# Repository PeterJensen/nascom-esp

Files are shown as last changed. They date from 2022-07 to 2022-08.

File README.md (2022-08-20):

A hardware emulator for the Nascom-2 computer running on an ESP-32 with:
* VGA for display output
* PS/2 keyboard for input
* SD card reader for tape input/output

## History
The Nascom-2 was an early (1979) Z80 based micro.  Most machine were homebuilt from a kit: https://en.wikipedia.org/wiki/Nascom_(computer_kit)

The one I built 40+ years ago still runs!

## Specs
The specs of a typical machine:
* 4MHz Z80 (an 8080 compatible chip from Zilog)
* 8K static RAM on motherboard
* 64K dynamic RAM on extension board
* Cassette tape used for storage
* NAS-SYS monitor in ROM (2K) 
* Microsoft Basic in ROM (8K)

## Software
Lots of excellent software was written for this machine; including Assemblers/Disassemblers, Pascal editors/compilers, text formatters, games, etc.

The BLS Pascal compiler/editor deserves a special mention.  In my opinion, this is one of the most impressive pieces of software written. It was implemented by Anders Hejlsberg.  It is the origin of the Turbo Pascal and Delphi lineage of Pascal (-like) compilers and generates executable Z80 code. It allows code to be written with a full screen editor, which was a major leap in programmer productivity at the time. A welcome reprive from the line-by-line editing for Basic programs. The compiler and editor was implemented in **12K of code**. You'll be hard pressed to write a hello-world program and compile it into less code with today's 'modern' development environments.

An excellent resource/archive for software is Tommy Thorn's [nascomhomepage](http://www.nascomhomepage.com).

## Diagram
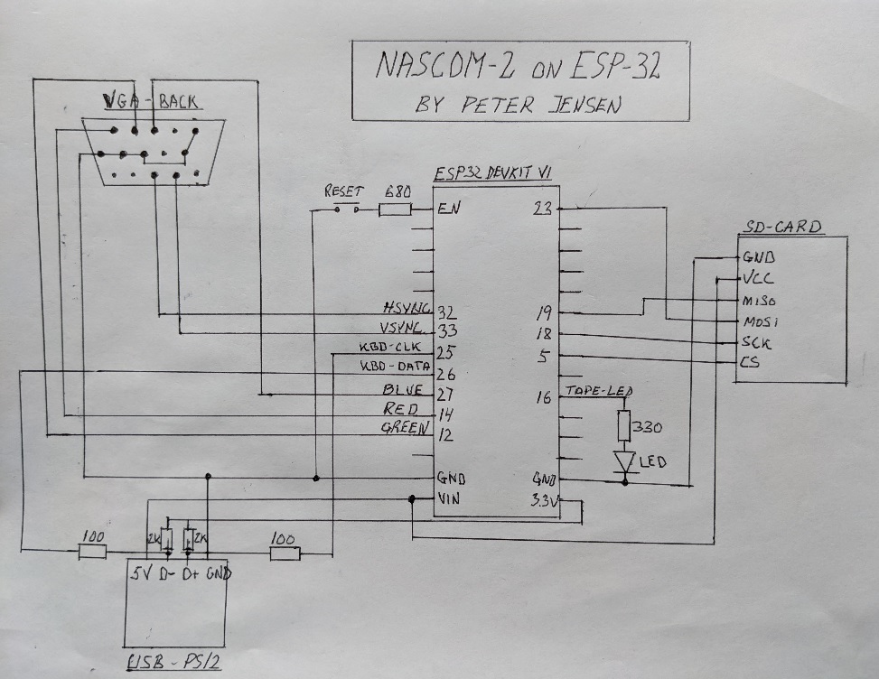
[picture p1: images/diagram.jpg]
Diagram


## Box
openSCAD was used to design a box, which can be printed on a 3D printer. I'm using the Creality Ender-3 printer, a very good budget printer (~$300).

I use openSCAD because doing the designs is much like writing code, so I don't have to step out of my comfort zone.

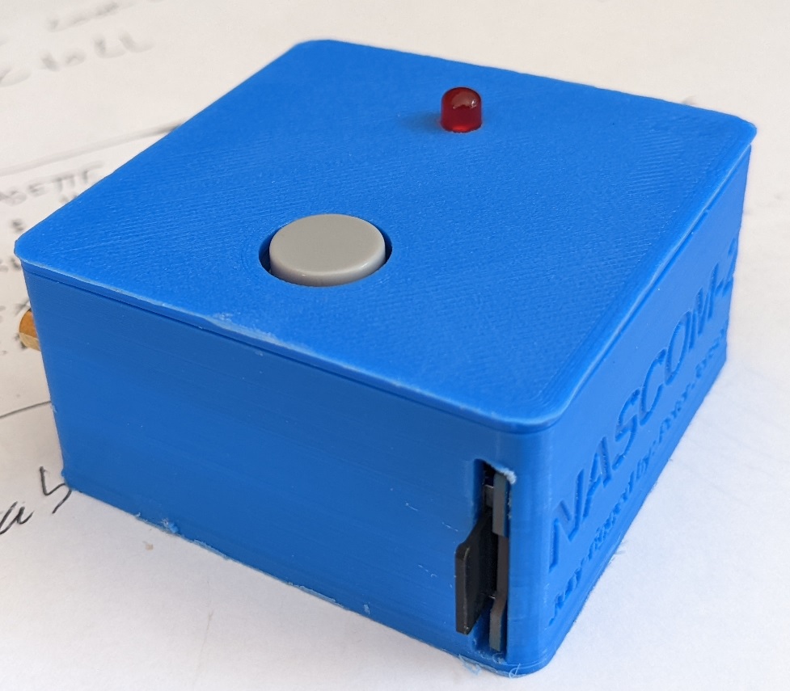
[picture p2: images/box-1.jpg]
Box 1

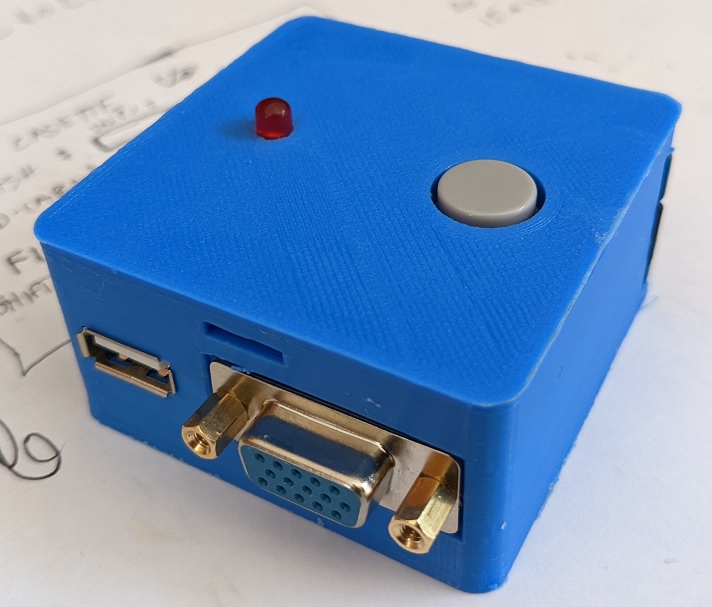
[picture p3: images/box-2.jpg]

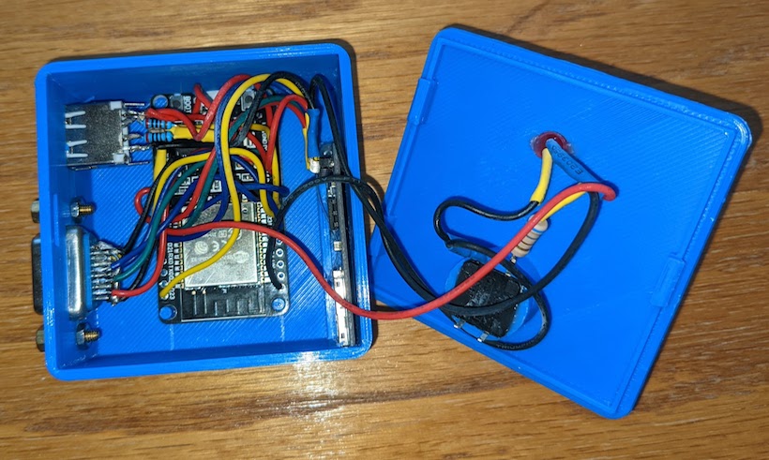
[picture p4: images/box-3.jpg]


## Screenshots
**Boot Screen**
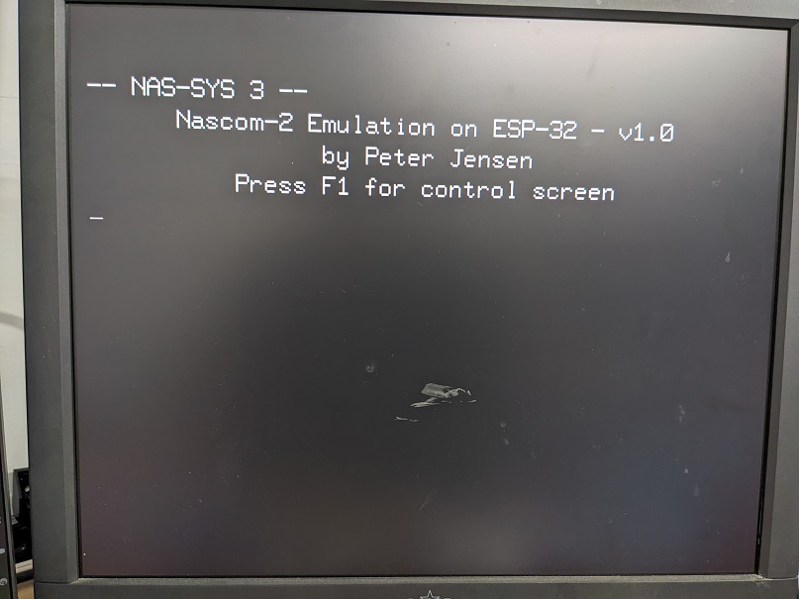
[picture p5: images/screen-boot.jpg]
Screen Boot


**Control Screen**
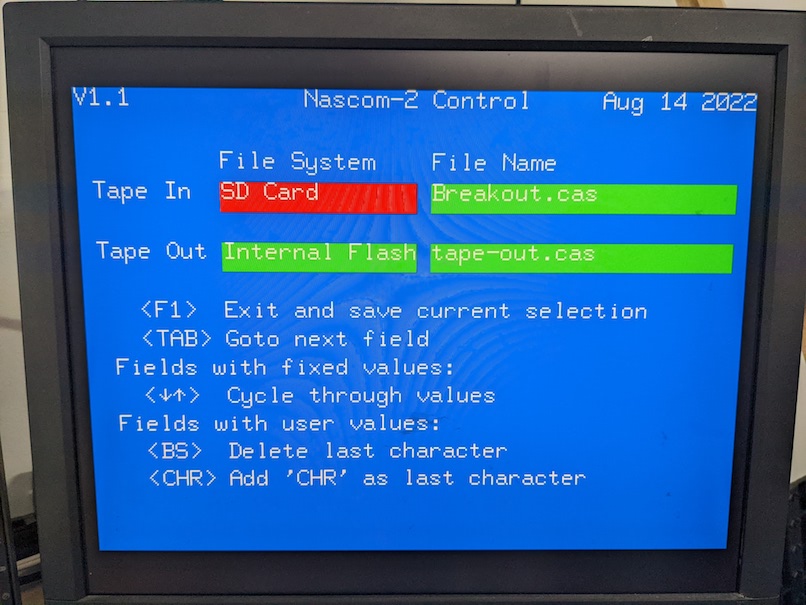
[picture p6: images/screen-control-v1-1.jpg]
Screen Control


**Loading and running BLS Pascal**
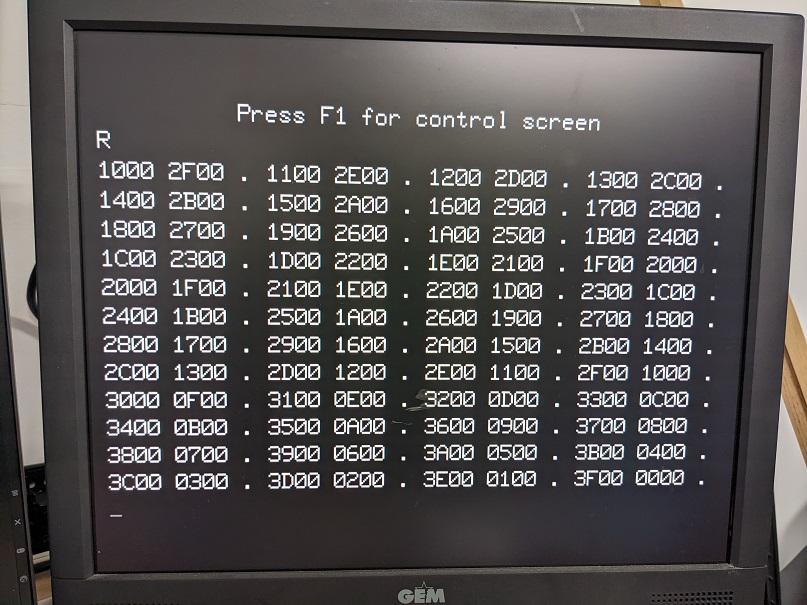
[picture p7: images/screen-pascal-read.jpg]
Screen Pascal Read

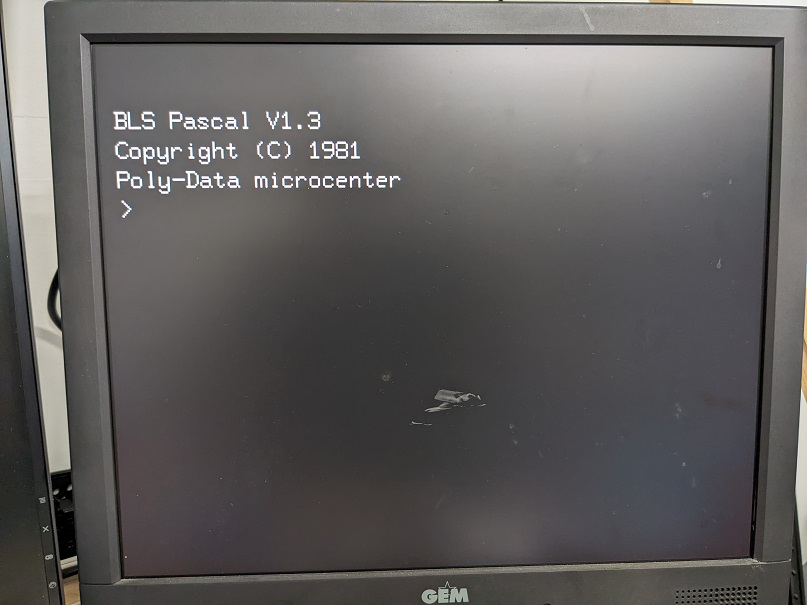
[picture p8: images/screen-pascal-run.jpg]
Screen Pascal Run

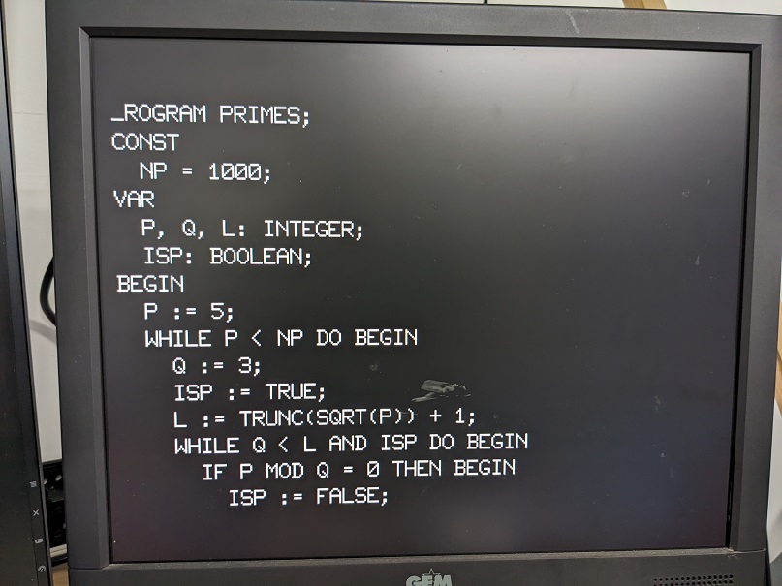
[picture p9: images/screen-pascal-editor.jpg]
Screen Pascal Editor

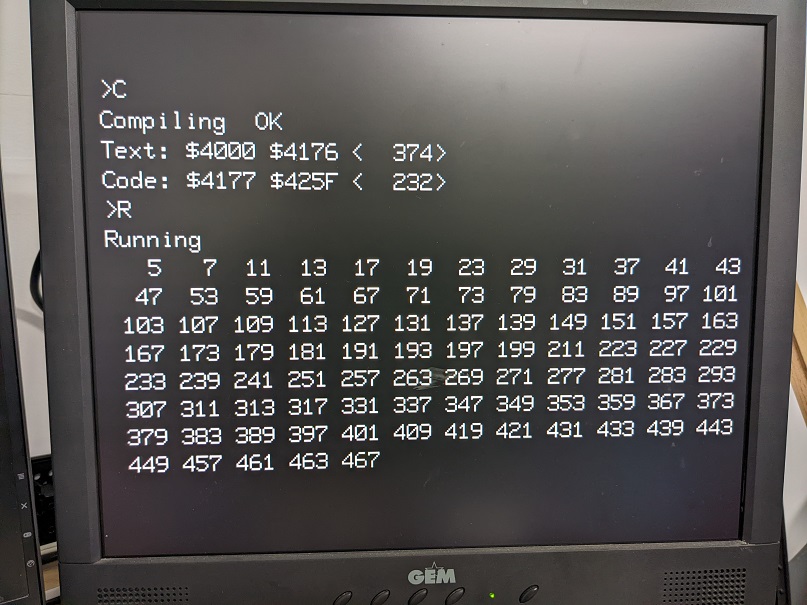
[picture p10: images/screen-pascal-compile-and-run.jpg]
Screen Pascal Compile


**NAP Assembler**
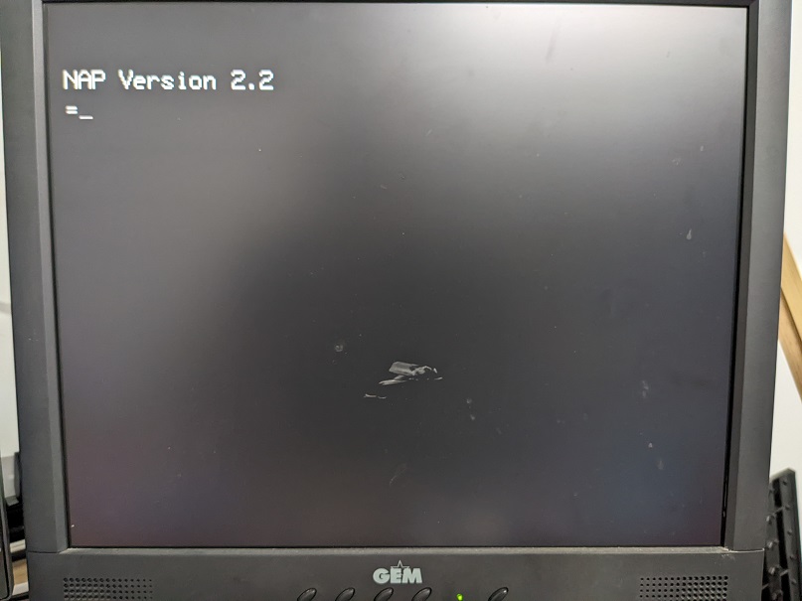
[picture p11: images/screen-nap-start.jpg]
Screen NAP

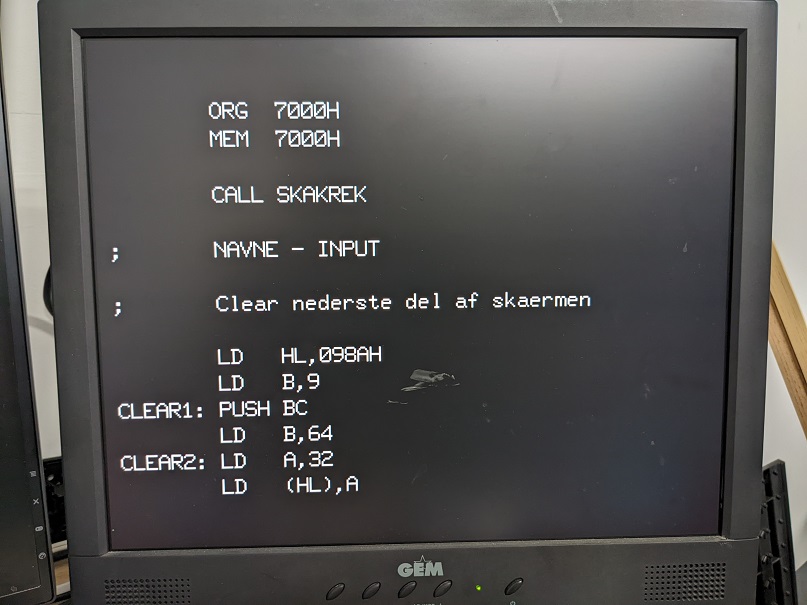
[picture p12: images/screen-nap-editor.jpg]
Screen NAP Editor

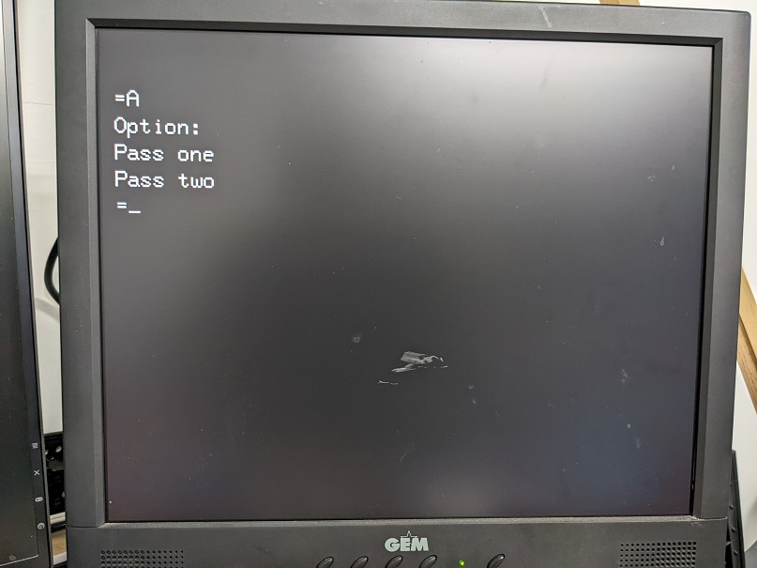
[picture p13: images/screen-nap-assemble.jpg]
Screen NAP Assemble

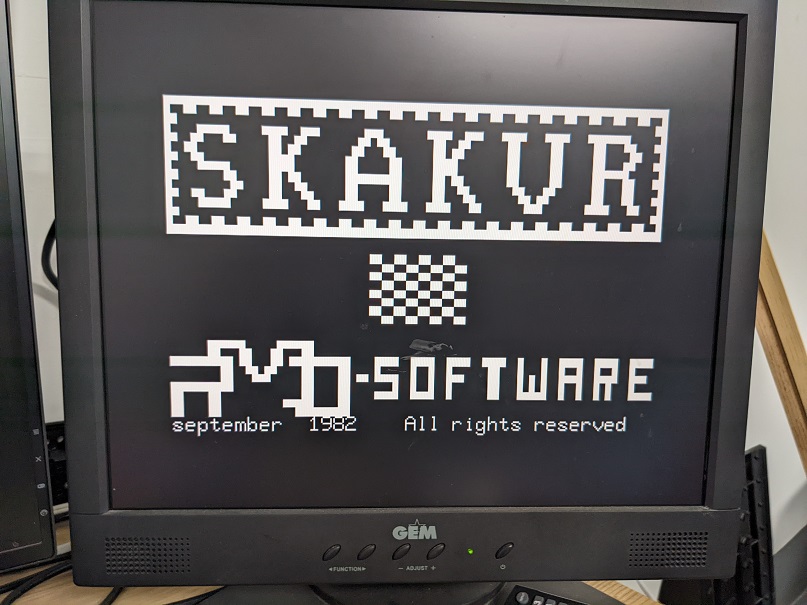
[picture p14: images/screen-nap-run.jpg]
Screen NAP Run


**Microsoft Basic**
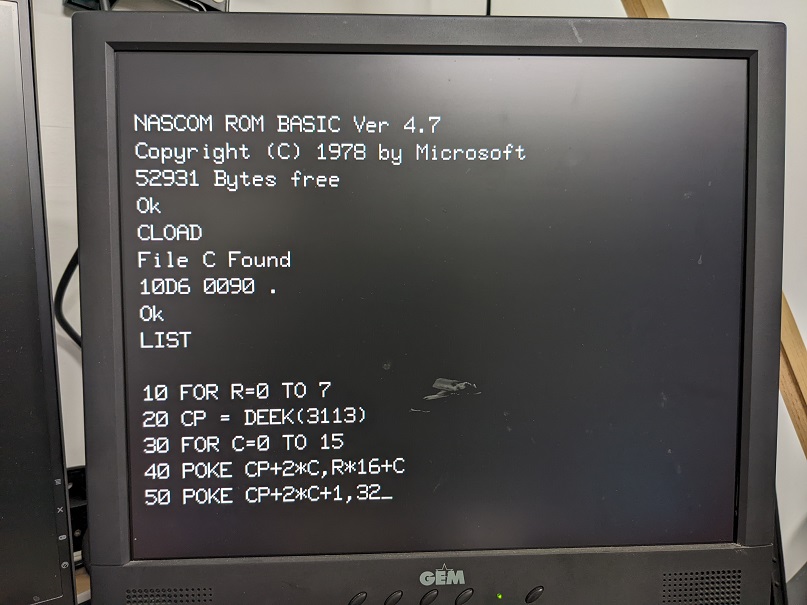
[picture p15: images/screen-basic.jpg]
Screen Basic Startup

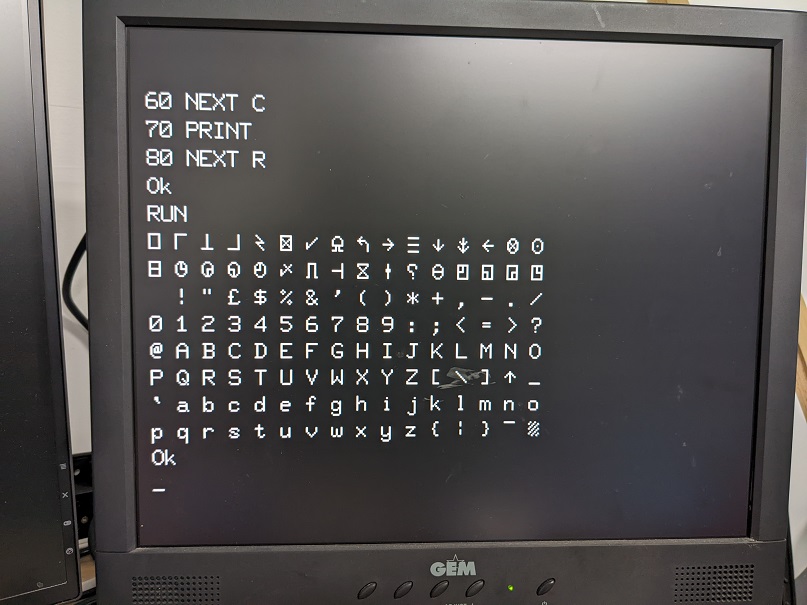
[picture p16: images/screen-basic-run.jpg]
Screen Basic Run


**nasForth**

Forth was also available on the Nascom-2.  Several implementations were made.  There's three (HullForth, nasForth, and T-Forth) on [nascomhomepage](http://www.nascomhomepage.com).  I've added nasForth to the permanent selection in the Internal Flash.

The Forth programming system had an innovative way of allowing the user to progressively develop their programs through compilation of word definitions and invocation of those definitions via a runtime interpreter.

With that said, I wouldn't recommend using Forth for anything substantial.  As a programming language, it has many drawbacks; mainly it's hard to write and read.  It took me many hours to get the PRIMES algorithm below working, and I even had a headstart, because I found some code on Youtube from [ForthFreak](https://www.youtube.com/watch?v=V5VGuNTrDL8).  I'm not a seasoned Forth programmer, though.  Not a Forth programmer at all, actually.  It is a great language, if you want to impress friends and colleagues with your mad obscure coding skills.

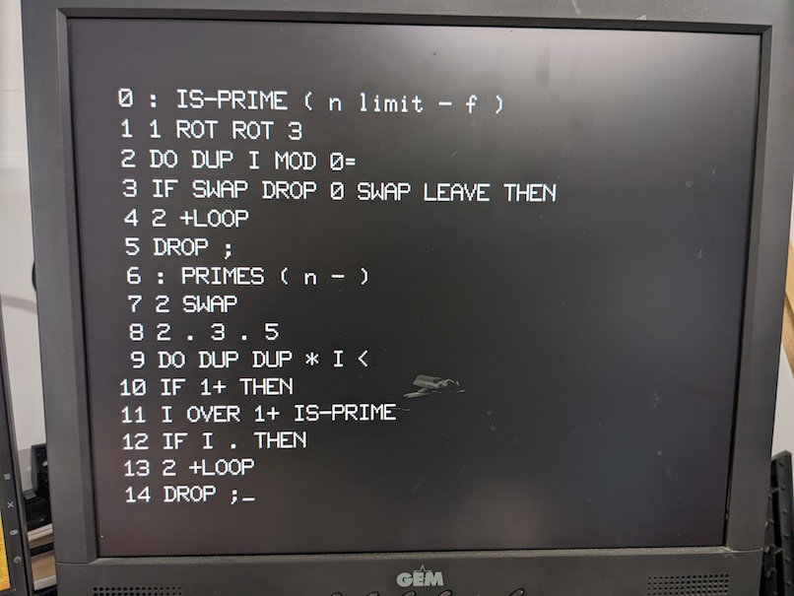
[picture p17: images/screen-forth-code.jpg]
Screen Forth Code

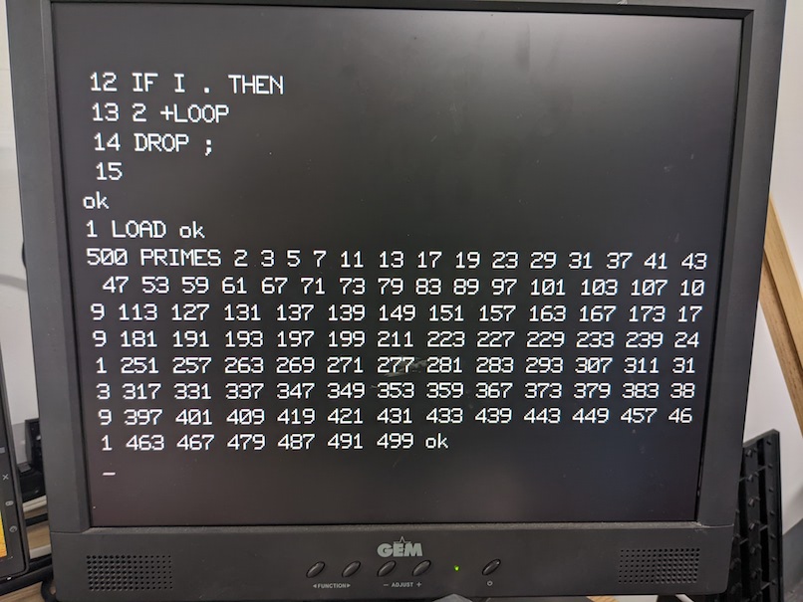
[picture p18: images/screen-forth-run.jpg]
Screen Forth Run


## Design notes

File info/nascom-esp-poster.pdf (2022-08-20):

# NASCOM-2 Replica on ESP32

by Peter Jensen
Specs:
- ESP32 Devkit V1
- VGA Display
- PS/2 Keyboard
- SD card for cassette tape emulation
- Runs all legacy NASCOM-2 software via Z80 emulator

ESP32-WROOM-32 specs:
- Xtensa dual-core32-bit LX6 microprocessor, operating at 160 or 240 MHz
- Ultra low power (ULP) co-processor (handles PS/2 keyboard)
- 512K RAM (roughly 320K available)
- Flash Memory: 4M
- Runs FreeRTOS

Software:
- Microsoft Basic (anno 1978)
- Assemblers/Disassemblers
- Pascal Compiler (12K)
- Forth
- Games

Notes:
- The screen refreshes at 30fps.
- Accurate execution timing requires a ~25ms delay for each frame.
- Idling 75% of the time (25/33).
- The ESP32 has plenty of headroom when emulating a 4MHz Z80.

More Info:
- https://github.com/PeterJensen/nascom-esp

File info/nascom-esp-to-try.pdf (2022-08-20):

# NASCOM-2 on ESP32: Things to try

1. Play BLS Super Maanelander:
1.1. Press RESET - Button on top of box
1.2. Type ‘E1000’ - Start executing at address 1000H. Code is pre-loaded
2. Compile and Run a Pascal program:
2.1. | Press <F1> | - Select ‘blspascal13.cas’ from the Internal Flash for ‘Tape In’
2.2. | Press <F1> | - Exit control screen
2.3. | Type ‘R’ | - Read the BLS Pascal Compiler/Editor
2.4. Type ‘E1000’ - Start the BLS Pascal Compiler/Editor program
2.5. | Press <F1> | - Select ‘primes.pas’ from the Internal Flash for ‘Tape In’
2.6. | Press <F1> | - Exit control screen
2.7. | Type ‘L’ | - Load the primes.pas Pascal source into memory
2.8. | Type ‘E’ | - Start the editor to inspect the Pascal code
2.9. Type ‘CTRL/X’- Exit the editor
2.10. | Type ‘C’ | - Compile the source code
2.11. | Type ‘R’ | - Run the compiled code
2.12. | Type ‘E’ | - Invoke the editor
2.13. | Make edits | - Can you make it run faster? Use SHIFT/Arrow Keys to insert
| | or delete characters and lines.
3. Microsoft Basic:
3.1. | Press <F1> | - Select ‘primes.bas’ from the Internal Flash for ‘Tape In’
3.2. | Press <F1> | - Exit control screen
3.3. | Type ‘J’ | - Start Microsoft Basic
3.4. Type ‘CLOAD’ - Load the primes.bas basic program
3.5. | Type ‘LIST’ | - See the program source
3.6. | Type ‘RUN’ | - Run the program
3.7. | Make edits | - Insert lines by typing in a line number followed by some Basic
| | command.
4. nasForth (Forth system)
4.1. | Press <F1> | - Select ‘NForth.cas’ from the Internal Flash for ‘Tape In’
4.2. | Press <F1> | - Exit control screen
4.3. | Type ‘R’ | - Read the nasForth program
4.4. | Press <F1> | - Select the ‘primes.for’ from the Interna Flash for ‘Tape In’
4.5. | Type ‘R’ | - Read the Forth example code into memory
4.6. Type ‘E1000’ - Start the nasForth program
4.7. Type ‘1 LIST’ - Shows the two word definitions for IS-PRIME and PRIMES
4.8. Type ‘1 LOAD’- Loads/compiles the code
4.9. Type ‘200 PRIMES’ - Find all primes less than 200

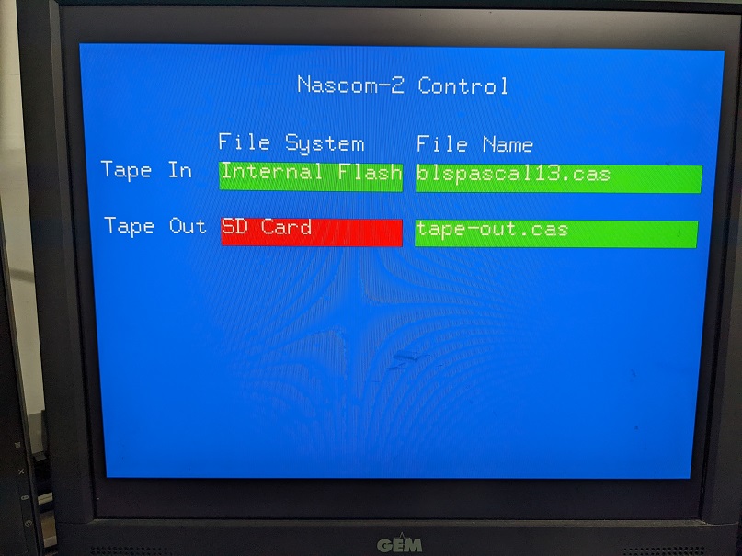
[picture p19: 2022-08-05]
images/screen-control.jpg

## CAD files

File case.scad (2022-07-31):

// Author: Peter Jensen

$fn = 50;
x = 0; y = 1; z = 2;

boxOuterDims        = [60.0, 60.0, 32.0];
boxWall             = 2;
boxInnerDims        = [boxOuterDims[x] - 2*boxWall, boxOuterDims[y] - 2*boxWall, boxOuterDims[z] - 2*boxWall];

esp32Dims           = [51.6, 28.2, 5.7];
esp32Offsets        = [boxOuterDims[x]/2 - esp32Dims[x]/2, 0, -boxInnerDims[z]/2 + esp32Dims[z]/2];
vgaPlateDims        = [31.8, 1.0, 13.4];
vgaConnectorDims    = [19.0, 16.5, 10.8];
vgaConnectorOffsets = [0, 6.2 - vgaConnectorDims[y]/2, 0];
vgaOffsets          = [-10.0, boxOuterDims[y]/2 - vgaPlateDims[y]/2, 0];
usbDims             = [13.0, 18.0, 5.6];
usbOffsets          = [18.0, boxOuterDims[y]/2 - usbDims[y]/2, vgaOffsets[z]];
sdDims              = [42.3, 3.0, 23.5];
sdPins              = [8.9, 6.5, 15.0];
sdBraceDims         = [sdDims[x] + 1, sdDims[y] + 3, 3];
sdBraceOffsets      = [-boxInnerDims[x]/2 + sdBraceDims[x]/2, -boxInnerDims[y]/2 + sdBraceDims[y]/2, -boxInnerDims[z]/2 + sdBraceDims[z]/2];
sdPinsOffsets       = [sdDims[x]/2 + sdPins[x]/2 - 5.2, -sdDims[y]/2 + sdPins[y]/2 - 1.0, 0];
sdOffsets           = [-boxOuterDims[x]/2 + sdDims[x]/2, -boxInnerDims[y]/2 + sdDims[y]/2 + 1, -boxInnerDims[z]/2 + sdDims[z]/2];
esp32HolesD         = 3;
esp32HolesOffset    = [2 - esp32Dims[x]/2, 2 - esp32Dims[y]/2, -esp32Dims[z]/2];
vgaHolesD           = 3.3;
vgaHolesOffsets     = [12.5, 0, 0];

// Reset switch/mount
switch2BaseDims     = [11.9, 11.9, 3.1];
switch2StemD        = 6.6;
switch2StemH        = 3.1;
switch2TopD         = 12.9;
switch2TopH         = 5.7;
switch2Z            = switch2BaseDims[z] + switch2StemH + switch2TopH - 1;
switchCylT          = 0.5;
  
module switch2() {
  translate([0, 0, switch2BaseDims[z]/2]) {
    cube(switch2BaseDims, center = true);
    translate([0, 0, switch2BaseDims[z]/2])
      cylinder(d = switch2StemD, h = switch2StemH, $fn = 40);
    translate([0, 0, switch2BaseDims[z]/2 + switch2StemH])
      cylinder(d = switch2TopD, h = switch2TopH, $fn = 40);
  }
}

switch2CylT      = 1.2;
switch2CylMargin = 1.0;
switch2CylZ      = switch2Z;
switch2CylD      = switch2TopD + switch2CylMargin;

resetMountOffsets = [-boxOuterDims[x]/4, 0, boxOuterDims[z]/2 - switch2Z];

module switch2Cyl() {
  translate([0, 0, 0]) {
    difference() {
      cylinder(d = switch2CylD + 2*switch2CylT, h = switch2Z, $fn = 40);
      translate([0, 0, switch2BaseDims[z]])
        cylinder(d = switch2CylD, h = switch2Z, $fn = 40);
      translate([0, 0, switch2BaseDims[z]/2])
        cube(switch2BaseDims, center = true);
    }
  }
}

module resetMount(cut = false, show = false) {
  translate(resetMountOffsets) {
    if (show)
      switch2();
    switch2Cyl();
    if (cut)
      cylinder(d = switch2CylD + 2*switchCylT, h = switch2CylZ);
  }
}

// Slots for top
slotZ        = 2;
slot1Dims    = [10, 2, 2];
slot1Offsets = [0, boxInnerDims[y]/2 + slot1Dims[y]/2, boxInnerDims[z]/2 - slot1Dims[z]/2 - slotZ];

slots2Dims    = [10, 1, 2];
slots2Offsets = [0, -boxInnerDims[y]/2 - slots2Dims[y]/2, boxInnerDims[z]/2 - slots2Dims[z]/2 - slotZ];
slots2Dist    = 30;

module slot1() {
  translate(slot1Offsets)
    cube(slot1Dims, center = true);
}

module slots2() {
  translate(slots2Offsets) {
    translate([-slots2Dist/2, 0, 0]) cube(slots2Dims, center = true);
    translate([slots2Dist/2, 0, 0]) cube(slots2Dims, center = true);
  }
}

module slots() {
  slot1();
  slots2();
}

boxRimDims = [boxInnerDims[x], boxInnerDims[y], 2];
boxRimInnerDims = boxRimDims - [2, 2, 0];

tapY1 = slot1Dims[z] + slotZ;
tapX2 = 2;
tapY2 = tapY1;
tapX3 = tapX2 + 1;
tapY3 = tapY2 - 1;
tapX4 = tapX2;
tapY4 = tapY3 - 1;
tapX5 = tapX2;
tapPoints = [[0, 0], [0, tapY1], [tapX2, tapY2], [tapX3, tapY3], [tapX4, tapY4], [tapX5, 0]];
tapW  = slot1Dims[x] - 1;

module tap() {
  rotate([-90, 0, 0])
    translate([0, 0, -tapW/2])
      linear_extrude(height = tapW)
        polygon(tapPoints);
}

module taps() {
  xOffset1 = boxRimDims[y]/2 - tapX2/2 - 0.5;
  xOffset2 = -boxRimDims[y]/2 + tapX2/2;
  yOffset  = boxRimDims[x]/2 - tapX2;
  zOffset  = boxInnerDims[z]/2;
//  tap();
  translate([0, yOffset, zOffset]) rotate([0, 0, 90]) tap();
  translate([slots2Dist/2, -yOffset, zOffset]) rotate([0, 0, -90]) tap();
  translate([-slots2Dist/2, -yOffset, zOffset]) rotate([0, 0, -90]) tap();
}


module esp32Holes(d = esp32HolesD) {
  translate(esp32HolesOffset)
    cylinder(d=d, h=esp32Dims[z]);
  translate([esp32HolesOffset[x], -esp32HolesOffset[y], esp32HolesOffset[z]])
    cylinder(d=d, h=esp32Dims[z]);
}

module esp32() {
  translate(esp32Offsets)
    difference() {
      cube(esp32Dims, center=true);
      esp32Holes();
    }
}

module vgaHoles(d = vgaHolesD) {
  module oneHole() {
    h = vgaPlateDims[y] + 5;
    translate([0, h/2, 0])
      rotate([90, 0, 0])
        cylinder(d = d, h = h);
  }
//  translate(vgaOffsets) {
    translate(vgaHolesOffsets)
      oneHole();
    translate([-vgaHolesOffsets[x], vgaHolesOffsets[y], vgaHolesOffsets[z]])
      oneHole();
//  }
}

module vga() {
  translate(vgaOffsets) {
    difference() {
      cube(vgaPlateDims, center=true);
      vgaHoles();
    }
    translate(vgaConnectorOffsets)
      cube(vgaConnectorDims, center=true);
  }
}

module usb() {
  translate(usbOffsets)
    cube(usbDims, center=true);
}

module sd() {
  translate(sdOffsets) {
    cube(sdDims, center=true);
    translate(sdPinsOffsets)
      cube(sdPins, center=true);
  }
}

module sdBrace() {
  difference() {
    translate(sdBraceOffsets)
      cube(sdBraceDims, center=true);
    sd();
  }
}

module components() {
    esp32();
    vga();
    usb();
    sd();
    translate(vgaOffsets)
      vgaHoles();
}


module roundedBox(dims, radius) {
  module cut() {
    difference() {
      cube([2*radius, 2*radius, dims[z]], center=true);
      translate([radius, radius, -dims[z]/2])
        cylinder(r=radius, h=dims[z], $fn=50);
    }
  }
  difference() {
    cube(dims, center=true);
    translate([-dims[x]/2, -dims[y]/2, 0])
      cut();
    translate([-dims[x]/2, dims[y]/2, 0])
      rotate([0, 0, -90]) cut();
    translate([dims[x]/2, -dims[y]/2, 0])
      rotate([0, 0, 90]) cut();
    translate([dims[x]/2, dims[y]/2, 0])
      rotate([0, 0, 180]) cut();
  }
}

module boxText(str, size = 8) {
  rotate([90, 0, 0])
    linear_extrude(height = 5)
      text(str, font="Ariel:style=Bold", size, halign="center", valign="center", spacing=0.95);
}

module nascomText() {
  translate([0, -boxOuterDims[y]/2 + 0.5, 5])
    boxText("NASCOM-2", 7.5);
}

module madeByText() {
  translate([0, -boxOuterDims[y]/2 + 0.5, -5])
    boxText("Jury-rigged by: Peter Jensen", 3);
}

module serialNoText() {
  translate([0, -boxOuterDims[y]/2 + 0.5, -11])
    boxText("Serial No.: 3", 3);
}
  
module boxBottom() {
  color([0.3, 0.5, 0.8, 1.0]) {
    difference() {    
      roundedBox(boxOuterDims, 4);
      cube(boxInnerDims, center=true);
      nascomText();
      madeByText();
      serialNoText();
      components();
      slots();
      translate([0, 0, boxOuterDims[z] - boxWall])
        cube(boxOuterDims, center=true);
    }
    sdBrace();
    translate(esp32Offsets)
      esp32Holes(esp32HolesD - 0.5);
  }
}

module boxTopRim() {
  translate([0, 0, boxInnerDims[z]/2 - boxRimDims[z]/2])
    difference() {
      cube(boxRimDims, center = true);
      cube(boxRimInnerDims, center = true);
    }
}

ledD = 4.9;
ledOffsets = [boxOuterDims[x]/4, 0, boxInnerDims[z]/2 + boxWall/2];
module led() {
  translate(ledOffsets)
    cylinder(d=ledD, h=boxWall, center=true);
}

module boxTop() {
  difference() {
    roundedBox(boxOuterDims, 4);
    translate([0, 0, -boxWall])
      cube(boxOuterDims, center=true);
    resetMount(true);
    led();
  }
  boxTopRim();
  resetMount();
  taps();
}

module main() {
  boxBottom();
  //components();
  //boxTop();
  //resetMount();
}

main();

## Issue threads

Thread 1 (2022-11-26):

Request for help in compiling Nascom-ESP

bob-g4bby, 2022-11-26:
Hi Peter,

I'm a numty when it comes to Visual Studio Code and PlatformIO. I downloaded your four files there - but PlatformIO complains it can't open file ESP32Lib.h nor devdrivers/keyboard.h . I used to have a Nascom and was hoping to emulate it using a TTGO based VGA32 board. I'll need to reassign some pins, but need to get you original code to compile first.

Any help would be appreciated - Bob Edwards, SW U.K.

PeterJensen, 2023-02-26:
Hi Bob,

So sorry for not getting back to you sooner.  I didn't see this issue until just now.

The code makes use of these two libraries:
- bitluni's ESP32Lib: https://github.com/bitluni/ESP32Lib
- Fabrizio Di Vittorio's FabGL: https://github.com/fdivitto/FabGL

You'll need to have a 'clones' directory at the same level as your nascom-esp clone.  Those two repos must be cloned into that clones directory.  Alternatively you can modify platformio.ini to point to where they can be found.

In addition, I've made a few changes to the repos mentioned above, so after you've created the clones you'll need to apply the two patches found in this repo, so something like this:

```
$ cd ESP32Lib
$ git apply ../../nascom-esp/ESP32Lib.patch
$ cd ../FabGL
$ git apply ../../nascom-esp/FabGL.patch

```
Hope this helps
Peter

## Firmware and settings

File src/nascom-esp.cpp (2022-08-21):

// Author: Peter Jensen
//
// NASCOM-2 Simulator running on an ESP32S
//
// The simulator uses a VGA display and a PS/2 keyboard.
// The cassette tape is simulated with both the internal flash and an attached SD card reader.
//
// PlatformIO/VS Code development environment was used for development.
//
// The project uses software from various sources:
//
// 1. Tommy Thorn's virtual-nascom: https://github.com/tommythorn/virtual-nascom:
//    Many concepts and ideas are derived from Tommy's original work:
//    Nascom-2 keyboard simulation:  Original code is mostly rewritten, but the ideas are the same.
//      Tommy's original code was instrumental in getting this right.  Also, his feedback and
//      debugging has been invaluable.
//    Video RAM update: The idea of caching.
//    CPU timing: Controlling timing with delays for each frame.
//    Nascom-2 font definition: Copied directly from above repo.
// 2. bitluni's ESP32Lib: https://github.com/bitluni/ESP32Lib:
//    VGA driver logic:  Made it work with the Nascom-2 font defintion from 1)
// 3. Fabrizio Di Vittorio's FabGL: https://github.com/fdivitto/FabGL:
//    PS/2 keyboard handling: This fabulous library does much more than just handling a PS/2
//      keyboard.  It's also able to handle the VGA and Z80 CPU simulation, but those
//      parts aren't used.  I'm considering using the Z80 simulator, since it tracks clock cycles,
//      so it should be possible to get a more accurate simulation of time.
// 4. Z80 emulator from Frank D. Cringle:
//    There are many Z80 emulator's to choose from.  This is the one used by virtual-nascom, and
//    I use it here as well.  It's been proven to work for NASCOM-2 simulation.
//
// Notes:
//
// 1. The display is set to be refreshed at 30fps. The number of instructions that will execute between
//    each frame is based on roughly 8 cycles per instructions and a clock frequency of 4MHz.
//    The necessary delay for each frame in order to get accurate simulation speed is dynamically
//    determined and turns out to be roughly 25ms.  So for each 33ms (a frame) the ESP32 is idling for
//    25ms. The ESP32 is more than capable of simulating a 4MHz Z80.
//

#include <Arduino.h>
#include <LittleFS.h>
#include <SD.h>
#include <SPI.h>
#include "ESP32Lib.h"
#include "devdrivers/keyboard.h"
#include "NascomFont.h"
#include "simz80.h"

#define VERSION "V1.1"
static const char *version = VERSION;
static const char *buildDate = __DATE__;

namespace z80 {
  // Z80 state
  WORD af[2];                  // accumulator and flags (2 banks)
  int af_sel;                  // bank select for af
  struct ddregs regs[2];       // bc,de,hl
  int regs_sel;                // bank select for ddregs
  WORD ir;                     // other Z80 registers
  WORD ix;
  WORD iy;
  WORD sp;
  WORD pc;
  WORD IFF;
  BYTE ram[MEMSIZE*1024+1];  // The +1 location is for the wraparound GetWord
};

static const char *startText =
  "      Nascom-2 Emulation on ESP-32 - " VERSION "\x17\x14"
  "          Press F1 for control screen\x17\x14";

// Pin configuration
class Pins {
public:
  static const gpio_num_t red      = GPIO_NUM_14;
  static const gpio_num_t green    = GPIO_NUM_12;
  static const gpio_num_t blue     = GPIO_NUM_27;
  static const gpio_num_t hsync    = GPIO_NUM_32;
  static const gpio_num_t vsync    = GPIO_NUM_33;
  static const gpio_num_t kbdClock = GPIO_NUM_25;
  static const gpio_num_t kbdData  = GPIO_NUM_26;
  static const gpio_num_t tapeLed  = GPIO_NUM_16;
  static const gpio_num_t sdSck    = GPIO_NUM_18;
  static const gpio_num_t sdMiso   = GPIO_NUM_19;
  static const gpio_num_t sdMosi   = GPIO_NUM_23;
  static const gpio_num_t sdCs     = GPIO_NUM_5;
};

// Nascom memory
class NascomMemory {
  uint8_t *mem;
public:
  NascomMemory(uint8_t *mem) : mem(mem) {}
  uint8_t *getMemPtr() {
    return mem;
  }
  bool nasFileLoad(const char *fileName) {
    uint16_t addr;
    File     file = LittleFS.open(fileName, "r");
    uint32_t numBytes = 0;
    if (!file) {
      DEBUG_PRINTF("Cannot open: %s\n", fileName);
      return false;
    }
    DEBUG_PRINTF("Loading %s\n", fileName);
    const size_t bufSize = 100;
    char buffer[bufSize];
    while (file.available()) {
      size_t l = file.readBytesUntil('\n', buffer, bufSize-1);
      buffer[l] = 0;
      if (buffer[0] == '.') {
        break;
      }
      char *p = buffer;
      addr  = strtoul(p, &p, 16);
      // DEBUG_PRINTF("%04x:", addr);
      for (uint8_t b = 0; b < 8; b++) {
        uint8_t byte = strtoul(p, &p, 16);
        mem[addr+b] = byte;
        if (addr + b == 0) {
          mem[0x10000] = mem[0]; // make getWord(0xffff) work correctly
        }
        // DEBUG_PRINTF(" %02x", byte);
      }
      // DEBUG_PRINTF("\n");
      numBytes += 8;
    }
    file.close();
    DEBUG_PRINTF("%d (%04x) bytes loaded\n", numBytes, numBytes);
    return true;
  }
};

// Nascom display
class NascomDisplay {
private:  
  static const uint32_t width      = 48;
  static const uint32_t height     = 16;
  static const uint32_t leftMargin = 1;
  static const uint32_t topMargin  = 1;
  VGA3Bit               vga;
  bool                  cacheInitialized = false;
  bool                  cacheUsed        = true;
  uint8_t               cache[width*height];
  uint32_t              cx = 0;
  uint32_t              cy = 0;
public:
  VGA3Bit::Color        white;
  VGA3Bit::Color        black;
  VGA3Bit::Color        red;
  VGA3Bit::Color        green;
  VGA3Bit::Color        blue;

  void init() {
    //vga.setFrameBufferCount(2);
    vga.init(vga.MODE400x300, Pins::red, Pins::green, Pins::blue, Pins::hsync, Pins::vsync);
    white = vga.RGB(255, 255, 255);
    black = vga.RGB(0, 0, 0);
    red   = vga.RGB(255, 0, 0);
    green = vga.RGB(0, 255, 0);
    blue  = vga.RGB(0, 0, 255);
    vga.setFont(NascomFont);
    vga.setTextColor(white, black);
  }

  void setTextColor(VGA3Bit::Color fg, VGA3Bit::Color bg) {
    vga.setTextColor(fg, bg);
  }

  void clear() {
    for (uint32_t y = 0; y < height; y++) {
      for (uint32_t x = 0; x < width; x++) {
        drawCharAt(x, y, ' ');
      }
    }
  }

  void show() {
    //vga.show();
  }
  void setCacheUsed(bool used) {
    cacheUsed = used;
  }
  void clearCache() {
    cacheInitialized = false;
  }
  void drawCharAt(uint32_t x, uint32_t y, uint8_t ch) {
    if (x < width && y < height) {
      vga.drawChar((x + leftMargin)*NascomFont.charWidth, (y + topMargin)*NascomFont.charHeight, ch);
    }
  }
  void drawTextAt(uint32_t x, uint32_t y, const char *text) {
    while (*text != 0) {
      drawCharAt(x, y, *text);
      x++;
      text++;
    }
  }
  void putChar(uint8_t ch) {
    drawCharAt(cx, cy, ch);
    cx += 1;
    if (cx >= width) {
      cx = 0;
      cy += 1;
      if (cy >= height) {
        cy = 0;
      }
    }
  }
  void updateFromMemory(NascomMemory &memory) {
    //DEBUG_PRINTF("NascomDisplay::updateFromMemory:\n");
    uint8_t *ram = memory.getMemPtr();
    for (uint8_t *p0 = ram + 0x80A;
        p0 < ram + 0xC00;
        p0 += 64) {
      //DEBUG_PRINTF("%04x:", p0 - ram);
      for (uint8_t *p = p0;
          p < p0 + 48;
          ++p) {
        uint32_t index = p - ram - 0x800;
        uint32_t x     = index % 64 - 10;
        uint32_t y     = index / 64;
        y = (y + 1) % 16; // The last line is the first line
        if (cacheUsed && !cacheInitialized) {
          cache[x + y*width] = *p;
        }
        if (cacheUsed && cacheInitialized) {
          if (cache[x + y*width] != *p) {
            drawCharAt(x, y, *p);
            cache[x + y*width] = *p;
          }
        }
        else {
          drawCharAt(x, y, *p);
        }
        //DEBUG_PRINTF(" %02x", *p);
      }
      //DEBUG_PRINTF("\n");
    }
    cacheInitialized = cacheUsed;
    show();
  }
};

class NascomTape {
  bool                  tapeLed        = false;
  static const uint32_t maxFileNameLen = 32;
  char                  inFileName[maxFileNameLen+1];
  char                  outFileName[maxFileNameLen+1];
  File  inFile;
  File  outFile;
  FS   *inFs;
  FS   *outFs;
  bool  filesAreOpen;
  bool  inIsOpen;
  bool  outIsOpen;
public:
//  NascomTape() : tapeLed(false), inFileIsOpen(false), outFileIsOpen(false) {}
  void init() {
    pinMode(Pins::tapeLed, OUTPUT);
    inFileName[0] = 0;
    outFileName[0] = 0;
    filesAreOpen = false;
    inIsOpen = false;
    outIsOpen = false;
  }
  void setLed(bool isOn) {
    tapeLed = isOn;
    digitalWrite(Pins::tapeLed, isOn ? HIGH : LOW);
  }
  bool getLed() {
    return tapeLed;
  }
  void setOutputFile(FS *fs, const char *fileName) {
    outFs = fs;
    if (fileName[0] != '/') {
      outFileName[0] = '/';
      strncpy(&(outFileName[1]), fileName, maxFileNameLen-1);
    }
    else
      strncpy(outFileName, fileName, maxFileNameLen);
    outFileName[maxFileNameLen] = 0;
    DEBUG_PRINTF("setOutputFile: %s\n", outFileName);
  }
  void setInputFile(FS *fs, const char *fileName) {
    inFs = fs;
    if (fileName[0] != '/') {
      inFileName[0] = '/';
      strncpy(&(inFileName[1]), fileName, maxFileNameLen-1);
    }
    else
      strncpy(inFileName, fileName, maxFileNameLen);
    inFileName[maxFileNameLen] = 0;
    DEBUG_PRINTF("setInputFile: %s\n", inFileName);
  }
  void closeFiles() {
    DEBUG_PRINTF("closeFiles\n");
    if (!inIsOpen && !outIsOpen) {
      DEBUG_PRINTF("closeFiles: Nothing to do\n");
      return;
    }
    if (inFile) {
      inFile.close();
    }
    if (outFile) {
      outFile.close();
    }
    filesAreOpen = false;
    inIsOpen = false;
    outIsOpen = false;
  }
  bool hasData() {
    return inFile && inFile.available();
  }

  uint8_t readByte() {
    if (!tapeLed)
      return 0;
    if (!inIsOpen) {
      inFile = inFs->open(inFileName, "r");
      DEBUG_PRINTF("readByte: Opening %s => %s\n", inFileName, inFile ? "true" : "false");
      inIsOpen = true;
    }
    if (!inFile.available()) {
      inFile.seek(0);
    }
    return inFile.read();
  }
  void writeByte(uint8_t b) {
  //  DEBUG_PRINTF("writeByte: %02x\n", b);
    if (!tapeLed)
      return;
    if (!outIsOpen) {
      if (outFs->exists(outFileName)) {
        outFile = outFs->open(outFileName, "r");
        size_t size = outFile.size();
        outFile.close();
        // Saving Basic files is done in two tape write operations
        //   1. A header (0xd3 0xd3 0xd3 'X') 4 bytes is written
        //   2. The content is written in the NASSYS Write format
        // In order not to lose the header, the file must be appended to
        if (size < 16)
          outFile = outFs->open(outFileName, "a"); 
        else
          outFile = outFs->open(outFileName, "w");
      }
      else
        outFile = outFs->open(outFileName, "w");
      DEBUG_PRINTF("writeByte: Opening %s => %s\n", outFileName, outFile ? "true" : "false");
      outIsOpen = true;
    }
    if (outFile) {
      outFile.write(b);
    }
  }
};

// Nascom Control
// UI for picking tape i/o files

class NascomControl {
  NascomDisplay        &display;
  NascomTape           &tape;
  static NascomControl *self;
  bool                  isActive = false;
  static bool           hasSd;

  class FieldValues {
  protected:
    const char **values = nullptr;
    uint32_t     numValues = 0;
    uint32_t     current = 0;
    bool         refreshed = false;
  public:
    virtual void refresh() = 0;

    const char *getCurrent() {
      if (numValues == 0)
        return "";
      else
        return values[current];
    }
    const char *getNext() {
      current += 1;
      if (current == numValues) {
        current = 0;
      }
      return getCurrent();
    }
    const char *getPrev() {
      if (current == 0) {
        current = numValues;
      }
      current -= 1;
      return getCurrent();
    }
    void reset() {
      current = 0;
    }
    bool isRefreshed() {
      return refreshed;
    }
  };

  class TapeFsValues : public FieldValues {
  public:
    void refresh() {
      DEBUG_PRINTF("TapeFsValues::refresh\n");
      if (values != nullptr) {
        free(values);
      }
      values = (const char **)malloc(2*sizeof(void *));
      bool hasInternal = true; //LittleFS.begin();
      if (hasSd) {
        sdcard_type_t cardType = SD.cardType();
        if (cardType == CARD_NONE || cardType == CARD_UNKNOWN) {
          hasSd = false;
        }
      }
      numValues = 0;
      if (hasInternal) {
        values[numValues] = "Internal Flash";
        numValues += 1;
      }
      if (hasSd) {
        values[numValues] = "SD Card";
        numValues += 1;
      }
      this->reset();
      refreshed = true;
    }
  };
  class FileNames {
  public:
    static bool includeFile(File file) {
      const char *name = file.name();
      return (name != nullptr) && (name[0] != '.');
    }
    static uint32_t fileCount(File dir) {
      uint32_t count = 0;
      dir.rewindDirectory();
      while (File file = dir.openNextFile()) {
        if (includeFile(file))
          count += 1;
        file.close();
      }
      return count;
    }
    static const char **makeFileNames(File dir, uint32_t *count) {
      *count = fileCount(dir);
      char const **names = (const char **)malloc((*count)*sizeof(char *));
      uint32_t fileNum = 0;
      dir.rewindDirectory();
      while (File file = dir.openNextFile()) {
        if (!includeFile(file))
          continue;
        const char *name = file.name();
        char *nameValue = (char *)malloc(strlen(name)+1);
        strcpy(nameValue, name);
        names[fileNum] = nameValue;
        fileNum += 1;
        file.close();
      }
      return names;
    }
    static void freeFileNames(const char **names, uint32_t count) {
      for (uint32_t vi = 0; vi < count; vi++)
        free((void *)names[vi]);
      free(names);
    }

  };
  class TapeFileNamesSd : public FieldValues, public FileNames {
  public:
    void refresh() {
      DEBUG_PRINTF("TapeFileNamesSd::refresh\n");
      if (values != nullptr) {
        freeFileNames(values, numValues);
      }
      if (!hasSd) {
        values = nullptr;
        numValues = 0;
        return;
      }
      File dir = SD.open("/");
      values = makeFileNames(dir, &numValues);
      dir.close();
      this->reset();
      refreshed = true;
    }
  };

  class TapeFileNamesInt : public FieldValues, public FileNames {
  public:
    void refresh() {
      DEBUG_PRINTF("TapeFileNamesInt::refresh\n");
      if (values != nullptr) {
        freeFileNames(values, numValues);
      }
      File dir = LittleFS.open("/");
      values = makeFileNames(dir, &numValues);
      dir.close();
      this->reset();
      refreshed = true;
    }
  };

  enum FieldNames {
    noField         = 0,
    tapeInFs        = 1,
    tapeInFileName  = 2,
    tapeOutFs       = 3,
    tapeOutFileName = 4,
    numFields       = 5 // pseudo field name
  };
  enum FieldType {
    withValues,
    withText
  };
  static const uint32_t maxTextFieldLen = 30;
  struct Field {
    uint32_t        x;
    uint32_t        y;
    uint32_t        length;
    VGA3Bit::Color  background;
    FieldType       type;
    const char     *text;
    char            textEdit[maxTextFieldLen + 1];
    uint32_t        textLastChar;
    FieldValues    *values = nullptr;
  };
  static const FieldNames firstField = tapeInFs;
  static const FieldNames lastField  = tapeOutFileName;

  enum FieldMove {
    current,
    next,
    prev
  };

  Field            fields[numFields];
  FieldNames       activeField = noField;
  TapeFsValues     tapeFsValues;
  TapeFileNamesSd  tapeFileNamesSd;
  TapeFileNamesInt tapeFileNamesInt;

  void addFieldWithValues(Field &field, uint32_t x, uint32_t y, uint32_t length, FieldValues *values) {
    field.x = x;
    field.y = y;
    field.length = length;
    field.background = display.green;
    field.values = values;
    field.type = withValues;
    if (values != nullptr)
      setFieldText(field, values->getCurrent());
    else
      setFieldText(field, "");
  }
  void addFieldWithText(Field &field, uint32_t x, uint32_t y, uint32_t length, const char *text) {
    field.x = x;
    field.y = y;
    field.length = length;
    field.background = display.green;
    field.type = withText;
    if (text != nullptr) {
      strncpy(field.textEdit, text, maxTextFieldLen);
      field.textEdit[maxTextFieldLen] = 0;
      field.textLastChar = strlen(text);
    }
    else {
      field.textEdit[0] = 0;
      field.textLastChar = 0;
    }
    setFieldText(field, field.textEdit);
  }

  void setFieldText(Field &field, const char *text) {
    field.text = text;
    refreshField(field);
  }
  void refreshField(Field &field) {
    bool filling = false;
    display.setTextColor(display.white, field.background);
    for (uint32_t xi = 0; xi < field.length; xi++) {
      if (!filling && field.text[xi] == 0)
        filling = true;
      if (filling)
        display.drawCharAt(field.x + xi, field.y, ' ');
      else
        display.drawCharAt(field.x + xi, field.y, field.text[xi]);
    }
  }
  void setActiveField(FieldNames fieldName) {
    if (fieldName == noField) {
      activeField = fieldName;
    }
    else if (activeField != fieldName) {
      fields[activeField].background = display.green;
      refreshField(fields[activeField]);
      activeField = fieldName;
      fields[activeField].background = display.red;
      refreshField(fields[activeField]);
    }
  }
  void gotoNextField() {
    FieldNames nextField;
    if (activeField == lastField)
      nextField = firstField;
    else
      nextField = static_cast<FieldNames>(static_cast<uint32_t>(activeField) + 1);
    setActiveField(nextField);
  }
  void updateFieldValues(FieldNames fieldName, FieldValues *values) {
    DEBUG_PRINTF("updateFieldValues: %d\n", fieldName);
    fields[fieldName].values = values;
    updateFieldValue(fieldName, current);
  }
  void updateFieldValue(FieldNames fieldName, FieldMove move) {
    DEBUG_PRINTF("updateFieldValue: %d\n", fieldName);
    Field &field = fields[fieldName];
    if (field.type != withValues)
      return;
    FieldValues *values = fields[fieldName].values;
    const char  *newValue = nullptr; 
    if (values != nullptr) {
      if (move == current)
        newValue = values->getCurrent();
      else if (move == next)
        newValue = values->getNext();
      else // if (move == prev)
        newValue = values->getPrev();
      setFieldText(field, newValue);
      if (fieldName == tapeInFs) {
        if (newValue[0] == 'I') //
          updateFieldValues(tapeInFileName, &tapeFileNamesInt);
        else 
          updateFieldValues(tapeInFileName, &tapeFileNamesSd);
      }
    }
    else
      setFieldText(fields[activeField], "");
  }
  void updateFieldText(FieldNames fieldName, uint8_t c) {
    Field &field = fields[fieldName];
    if (field.type != withText)
      return;
    if (c == 0x08) {
      // backspace
      DEBUG_PRINTF("updateFieldText: backspace\n", c);
      if (field.textLastChar > 0) {
        field.textLastChar -= 1;
        field.textEdit[field.textLastChar] = 0;
        setFieldText(field, field.textEdit);
      }
    }
    else if (c > 32 && c < 127) {
      DEBUG_PRINTF("updateFieldText: %c\n", c);
      if (field.textLastChar < maxTextFieldLen) {
        field.textEdit[field.textLastChar] = c;
        field.textLastChar += 1;
        setFieldText(field, field.textEdit);
      }
    }
  }
  const char *getFieldText(FieldNames fieldName) {
    return fields[fieldName].text;
  }
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
void loop() {
  // Should never get here
  vTaskSuspend(NULL);
}

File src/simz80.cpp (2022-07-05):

/* Z80 instruction set simulator.
   Copyright (C) 1995  Frank D. Cringle.

This file is part of yaze - yet another Z80 emulator.

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
You should have received a copy of the GNU General Public License
along with this program; if not, write to the Free Software
Foundation, Inc., 59 Temple Place - Suite 330, Boston, MA 02111-1307, USA. */

/* This file was generated from simz80.pl
   with the following choice of options */
const char *perl_params =
    "combine=0,"
    "optab=0,"
    "cb_inline=0,"
    "dfd_inline=0,"
    "ed_inline=1";

#include "simz80.h"

namespace z80 {
static const unsigned char partab[256] = {
	4,0,0,4,0,4,4,0,0,4,4,0,4,0,0,4,
	0,4,4,0,4,0,0,4,4,0,0,4,0,4,4,0,
	0,4,4,0,4,0,0,4,4,0,0,4,0,4,4,0,
	4,0,0,4,0,4,4,0,0,4,4,0,4,0,0,4,
	0,4,4,0,4,0,0,4,4,0,0,4,0,4,4,0,
	4,0,0,4,0,4,4,0,0,4,4,0,4,0,0,4,
	4,0,0,4,0,4,4,0,0,4,4,0,4,0,0,4,
	0,4,4,0,4,0,0,4,4,0,0,4,0,4,4,0,
	0,4,4,0,4,0,0,4,4,0,0,4,0,4,4,0,
	4,0,0,4,0,4,4,0,0,4,4,0,4,0,0,4,
	4,0,0,4,0,4,4,0,0,4,4,0,4,0,0,4,
	0,4,4,0,4,0,0,4,4,0,0,4,0,4,4,0,
	4,0,0,4,0,4,4,0,0,4,4,0,4,0,0,4,
	0,4,4,0,4,0,0,4,4,0,0,4,0,4,4,0,
	0,4,4,0,4,0,0,4,4,0,0,4,0,4,4,0,
	4,0,0,4,0,4,4,0,0,4,4,0,4,0,0,4,
};

#define parity(x)	partab[(x)&0xff]

#ifdef DEBUG
volatile int stopsim;
#endif

#define POP(x)	do {							\
	FASTREG y = RAM(SP); SP++;					\
	x = y + (RAM(SP) << 8); SP++;					\
} while (0)

#define PUSH(x) do {							\
	--SP; RAM(SP) = (x) >> 8;					\
	--SP; RAM(SP) = x;						\
} while (0)

#define JPC(cond) PC = cond ? GetWORD(PC) : PC+2

#define CALLC(cond) {							\
    if (cond) {								\
	FASTREG adrr = GetWORD(PC);					\
	PUSH(PC+2);							\
	PC = adrr;							\
    }									\
    else								\
	PC += 2;							\
}

/* load Z80 registers into (we hope) host registers */
#define LOAD_STATE()							\
    PC = pc;								\
    AF = af[af_sel];							\
    BC = regs[regs_sel].bc;						\
    DE = regs[regs_sel].de;						\
    HL = regs[regs_sel].hl;						\
    SP = sp

/* load Z80 registers into (we hope) host registers */
#define DECLARE_STATE()							\
    FASTREG PC = pc;							\
    FASTREG AF = af[af_sel];						\
    FASTREG BC = regs[regs_sel].bc;					\
    FASTREG DE = regs[regs_sel].de;					\
    FASTREG HL = regs[regs_sel].hl;					\
    FASTREG SP = sp

/* save Z80 registers back into memory */
#define SAVE_STATE()							\
    pc = PC;								\
    af[af_sel] = AF;							\
    regs[regs_sel].bc = BC;						\
    regs[regs_sel].de = DE;						\
    regs[regs_sel].hl = HL;						\
    sp = SP

static void
cb_prefix(FASTREG adr)
{
    DECLARE_STATE();
    FASTWORK temp = 0, acu = 0, op, cbits;

		switch ((op = GetBYTE(PC)) & 7) {
		case 0: ++PC; acu = hreg(BC); break;
		case 1: ++PC; acu = lreg(BC); break;
		case 2: ++PC; acu = hreg(DE); break;
		case 3: ++PC; acu = lreg(DE); break;
		case 4: ++PC; acu = hreg(HL); break;
		case 5: ++PC; acu = lreg(HL); break;
		case 6: ++PC; acu = GetBYTE(adr); break;
		case 7: ++PC; acu = hreg(AF); break;
		}
		switch (op & 0xc0) {
		case 0x00:		/* shift/rotate */
			switch (op & 0x38) {
			case 0x00:	/* RLC */
				temp = (acu << 1) | (acu >> 7);
				cbits = temp & 1;
				goto cbshflg1;
			case 0x08:	/* RRC */
				temp = (acu >> 1) | (acu << 7);
				cbits = temp & 0x80;
				goto cbshflg1;
			case 0x10:	/* RL */
				temp = (acu << 1) | TSTFLAG(C);
				cbits = acu & 0x80;
				goto cbshflg1;
			case 0x18:	/* RR */
				temp = (acu >> 1) | (TSTFLAG(C) << 7);
				cbits = acu & 1;
				goto cbshflg1;
			case 0x20:	/* SLA */
				temp = acu << 1;
				cbits = acu & 0x80;
				goto cbshflg1;
			case 0x28:	/* SRA */
				temp = (acu >> 1) | (acu & 0x80);
				cbits = acu & 1;
				goto cbshflg1;
			case 0x30:	/* SLIA */
				temp = (acu << 1) | 1;
				cbits = acu & 0x80;
				goto cbshflg1;
			case 0x38:	/* SRL */
				temp = acu >> 1;
				cbits = acu & 1;
			cbshflg1:
				AF = (AF & ~0xff) | (temp & 0xa8) |
					(((temp & 0xff) == 0) << 6) |
					parity(temp) | !!cbits;
			}
			break;
		case 0x40:		/* BIT */
			if (acu & (1 << ((op >> 3) & 7)))
				AF = (AF & ~0xfe) | 0x10 |
				(((op & 0x38) == 0x38) << 7);
			else
				AF = (AF & ~0xfe) | 0x54;
			if ((op&7) != 6)
				AF |= (acu & 0x28);
			temp = acu;
			break;
		case 0x80:		/* RES */
			temp = acu & ~(1 << ((op >> 3) & 7));
			break;
		case 0xc0:		/* SET */
			temp = acu | (1 << ((op >> 3) & 7));
			break;
		}
		switch (op & 7) {
		case 0: Sethreg(BC, temp); break;
		case 1: Setlreg(BC, temp); break;
		case 2: Sethreg(DE, temp); break;
		case 3: Setlreg(DE, temp); break;
		case 4: Sethreg(HL, temp); break;
		case 5: Setlreg(HL, temp); break;
		case 6: PutBYTE(adr, temp);  break;
		case 7: Sethreg(AF, temp); break;
		}
    SAVE_STATE();
}

static FASTREG
dfd_prefix(FASTREG IXY)
{
    DECLARE_STATE();
    FASTWORK temp, adr, acu, op, sum, cbits;
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

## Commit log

2022-07-06 Started outline of case (openScad)
    [case.scad]
2022-07-13 Case/box enhancements
    [case.scad]
2022-07-14 Reset button for box
    [case.scad]
2022-07-15 Updated case/box
    [case.scad]
2022-07-17 Added holes for VGA connector
    [case.scad]
2022-07-17 Added SPI/SDCard pins
2022-07-18 Added lid slots to bottom part of case
    [case.scad]
2022-07-20 Made VGA plate a little bigger
    [case.scad]
2022-07-21 Made case bigger and rearranged parts
    [case.scad]
2022-07-22 Finished box top
    [case.scad]
2022-07-25 Added Serial No. to case
    [case.scad]
2022-07-31 Serial No 3 case version
    [case.scad]
2022-08-05 Fixed problem with 2 step saving process for Basic programs
    [nascom-esp.cpp]
2022-08-07 Fixed problems with SD.begin/end when the LED is used for sound in breakout
    [nascom-esp.cpp]
2022-08-08 Fixed the use of SHIFT-ENTER
    [nascom-esp.cpp]
2022-08-21 Fixed upper/lower case startText issue
    [nascom-esp.cpp]
2023-02-26 Added patch files for ESP32Lib and FabGL
2023-02-26 Updated ESP32Lib.patch

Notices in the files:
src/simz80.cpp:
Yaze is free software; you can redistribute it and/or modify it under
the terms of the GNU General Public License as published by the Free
